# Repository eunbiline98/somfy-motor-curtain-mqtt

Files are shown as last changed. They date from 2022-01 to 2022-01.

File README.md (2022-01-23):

# somfy-motor-curtain-mqtt
DIY Motorize Curtain Somfy Control Using Esp8266 MQTT Protocol
- Motorize Curtain Somfy Glydea                                       


Datasheet Motorize Curtain                                                     
- 
- https://www.somfypro.ca/documents/3931489/18635940/Glydea-Databook.pdf

List Item

- Esp8266 (Wemos D1 Mini)
- Optocoupler PC817
- Power Module Hi-Link 220VAC to 5VDC
- Resistor 1k 1/4 Watt
- Terminal Screw 2 Pin Hole

# Schematic
schematic

# Control
- Open Curtain
- Close Curtain
- Stop Curtain

# Home Assistant Setup 

Under covers in HA, use this config Motorize Curtain Control
```
  - platform: mqtt
    name: "Curtain Living Room"
    command_topic: "home/curtain/livingroom"
    state_topic: "home/curtain/state"
    qos: 0
    retain: true
    payload_open: "u"
    payload_close: "d"
    payload_stop: "s"
    state_open: "open"
    state_opening: "opening"
    state_closed: "closed"
    state_closing: "closing"
    optimistic: false
```

Under covers in HA, use this config MQTT

```
mqtt:
  broker: "Your IP Broker/server"
  port: Your port MQTT
  username: "Your username"
  password: Your password
  
```

# Documentation
https://user-images.githubusercontent.com/50385294/149776929-379bbfac-4cdb-4a9a-a8d9-ceeab45c952e.mp4

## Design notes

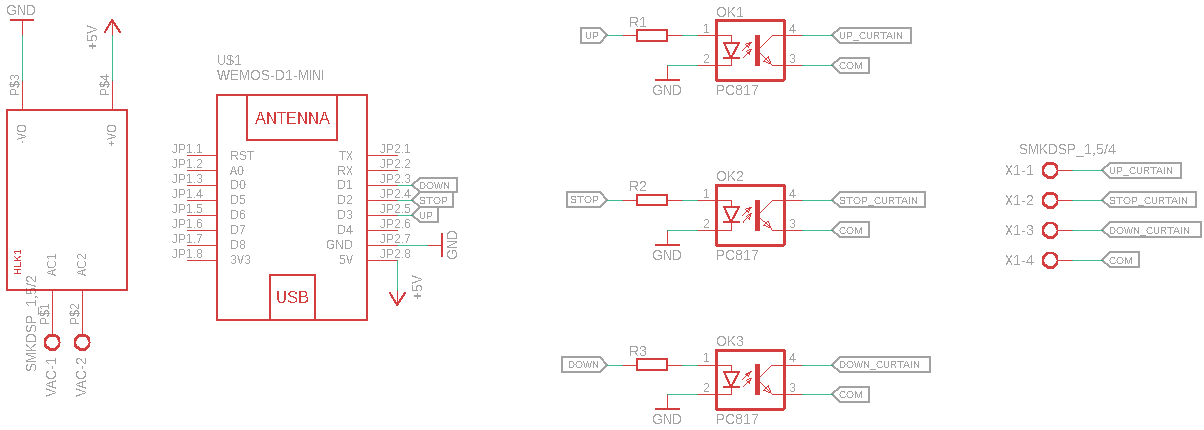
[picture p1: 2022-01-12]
schematic.png

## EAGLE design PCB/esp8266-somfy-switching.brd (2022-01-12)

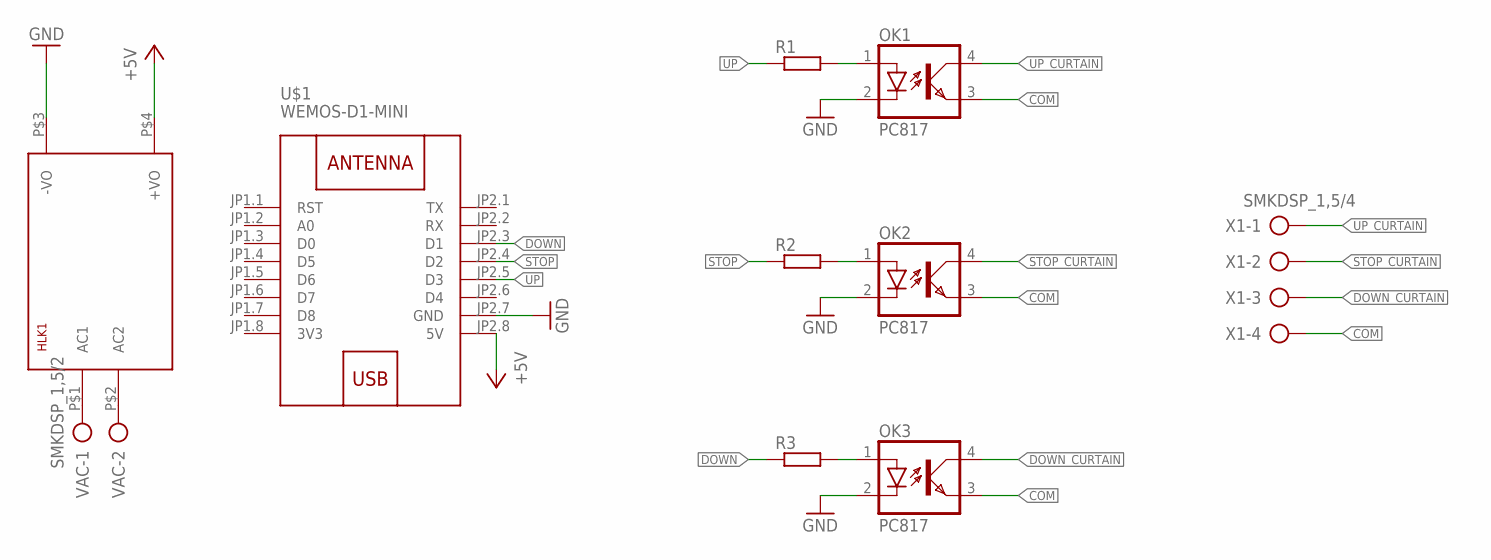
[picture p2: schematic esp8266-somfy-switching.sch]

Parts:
HLK1: HLK-PM013W; HLK-PM01
OK1, OK2, OK3: PC817; DIL04
R1, R2, R3: R-EU_0207/10; 0207/10
U$1: WEMOS-D1-MINI
VAC: SMKDSP_1,5/2
X1: SMKDSP_1,5/4

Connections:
3V3: U$1.JP1.8 (3V3)
+5V: HLK1.P$4 (+VO), U$1.JP2.8 (5V)
COM: OK1.3 (EMIT), OK2.3 (EMIT), OK3.3 (EMIT), X1.4
DOWN: R3.1, U$1.JP2.3 (D1)
DOWN_CURTAIN: OK3.4 (COL), X1.3
GND: HLK1.P$3 (-VO), OK1.2 (C), OK2.2 (C), OK3.2 (C), U$1.JP2.7 (GND)
unnamed: HLK1.P$1 (AC1), VAC.1
unnamed: HLK1.P$2 (AC2), VAC.2
unnamed: OK1.1 (A), R1.2
unnamed: OK2.1 (A), R2.2
unnamed: OK3.1 (A), R3.2
STOP: R2.1, U$1.JP2.4 (D2)
STOP_CURTAIN: OK2.4 (COL), X1.2
UP: R1.1, U$1.JP2.5 (D3)
UP_CURTAIN: OK1.4 (COL), X1.1

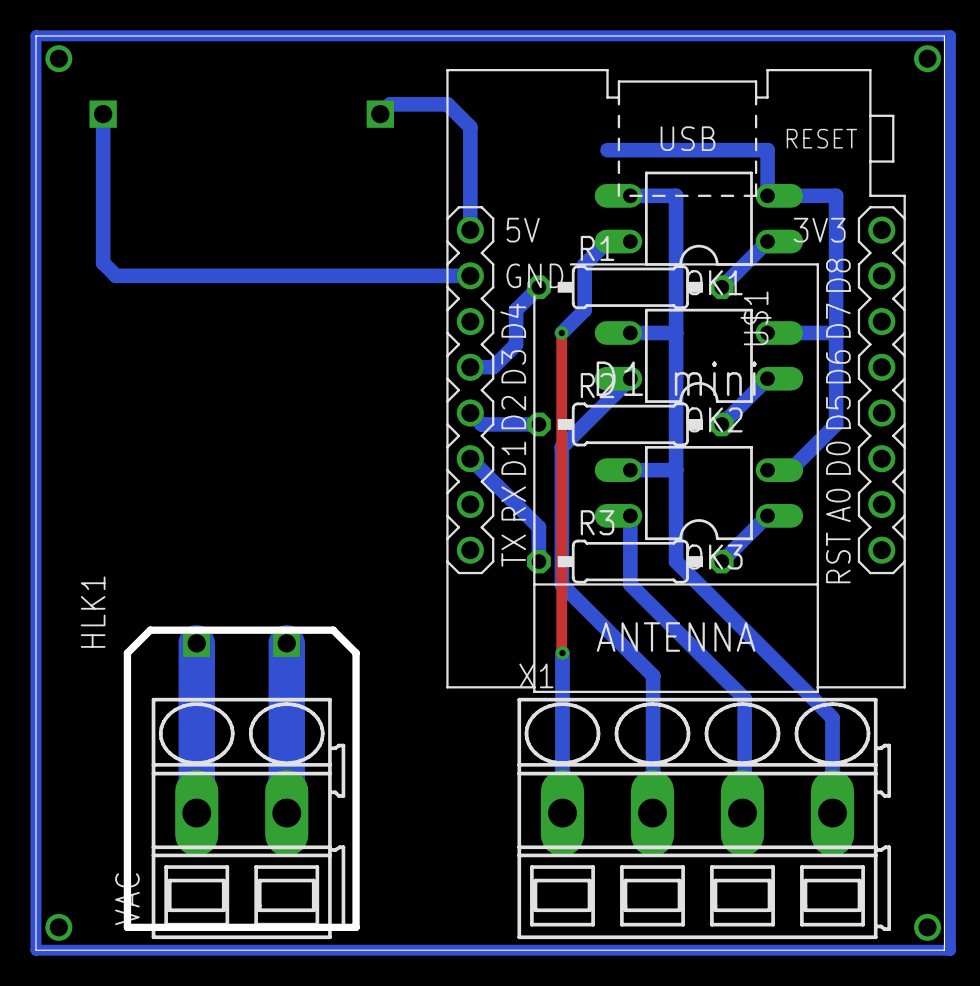
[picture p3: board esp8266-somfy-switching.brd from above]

Board: 2 copper layers, 50.5 x 50.8 mm, 10 parts (0 on the bottom side), 14 nets.

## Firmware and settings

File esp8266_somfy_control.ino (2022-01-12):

#include <ESP8266WiFi.h>
#include <PubSubClient.h>
#include <WiFiManager.h>
#include <Ticker.h>

const char *MQTT_SERVER = "xxx.xxx.xxx.xxx";
const char *MQTT_TOPIC_CURTAIN = "home/curtain/state";
const char *MQTT_STATUS_CURTAIN = "home/curtain/status";
const char *CURTAIN = "home/curtain/livingroom";

const char *MQTT_CLIENT_ID = "esp8266-somfy";
const char *MQTT_USERNAME = "";
const char *MQTT_PASSWORD = "";

char const* state_shutter;

WiFiClient espClient;
PubSubClient client(espClient);
Ticker ticker;

// Pin Setup
#define up D3
#define stopp D2
#define down D1

void tick()
{
  //toggle state
  digitalWrite(2, !digitalRead(2)); // set pin GPIO2 Led Wemos On-board
}

void configModeCallback(WiFiManager *myWiFiManager)
{
  Serial.println("Entered config mode");
  Serial.println(WiFi.softAPIP());
  //if you used auto generated SSID, print it
  Serial.println(myWiFiManager->getConfigPortalSSID());
  //entered config mode, make led toggle faster
  ticker.attach(0.2, tick);
}

void setup_wifi()
{
  WiFi.mode(WIFI_STA);
  pinMode(2, OUTPUT);
  ticker.attach(0.6, tick);

  WiFiManager wm;
  wm.setAPCallback(configModeCallback);

  bool res;
  res = wm.autoConnect("somfy_esp_WiFi");
  Serial.println(res  ? "Success!" : "Failed!");
  wm.debugSoftAPConfig();

  if (!res)
  {
    Serial.println("failed to connect");
    wm.resetSettings();
    ESP.restart();
    delay(1000);
  }

  Serial.println("connected...");
//  ticker.detach();
}

void callback(char *topic, byte *message, unsigned int length)
{ Serial.print("Message arrived in topic: ");
  Serial.println(topic);
  Serial.print("Message:");
  String messageTemp;

  for (int i = 0; i < length; i++)
  {
    Serial.print((char)message[i]);
    Serial.println();
    if ((char)message[i] != '"')
      messageTemp += (char)message[i];
  }

  if (String(topic) == CURTAIN)
  {
    // up cutrain
    if (messageTemp == "u") {
      digitalWrite(up, HIGH);
      delay(30);
      digitalWrite(up, LOW);
      state_shutter = "open";
    }
    // stop curtain
    else if (messageTemp == "s") {
      digitalWrite(stopp, HIGH);
      delay(30);
      digitalWrite(stopp, LOW);
      state_shutter = "stop";
    }
    // down curtain
    else if (messageTemp == "d") {
      digitalWrite(down, HIGH);
      delay(30);
      digitalWrite(down, LOW);
      state_shutter = "closed";
    }
    client.publish(MQTT_TOPIC_CURTAIN, state_shutter, true);
  }
}

void reconnect()
{
  // Loop until we're reconnected
  while (!client.connected())
  {
    Serial.print("Attempting MQTT connection...");
    // Attempt to connect
    if (client.connect(MQTT_CLIENT_ID, MQTT_USERNAME, MQTT_PASSWORD, MQTT_STATUS_CURTAIN, 1, 1, "Offline"))
    {
      Serial.println("connected");
      //subscribe
      client.subscribe(CURTAIN);
      client.publish(MQTT_STATUS_CURTAIN, "Online", true);
      digitalWrite(2, HIGH);
    }
    else
    {
      Serial.print("failed, rc=");
      Serial.print(client.state());
      Serial.println(" try again in 5 seconds");
      // Wait 5 seconds before retrying
      delay(5000);
    }
  }
}

void setup()
{
  // Serial port for debugging purposes
  Serial.begin(115200);
  setup_wifi();

  // MQTT Server Setup
  client.setServer(MQTT_SERVER, 1883);
  client.setCallback(callback);

  pinMode(2, OUTPUT); //WiFi Indicator
  pinMode(up, OUTPUT);
  pinMode(stopp, OUTPUT);
  pinMode(down, OUTPUT);

  digitalWrite(up, LOW);
  digitalWrite(stopp, LOW);
  digitalWrite(down, LOW);

}

void loop()
{
  if (!client.connected())
  {
    reconnect();
  }
  client.loop();
}

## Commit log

2022-01-12 Upload PCB Design
    [esp8266-somfy-switching.brd]
2022-01-12 Upload Schematic Design
    [esp8266-somfy-switching.sch]
2022-01-12 Adding Schematic

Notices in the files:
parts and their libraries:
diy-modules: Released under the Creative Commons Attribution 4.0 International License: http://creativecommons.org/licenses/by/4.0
